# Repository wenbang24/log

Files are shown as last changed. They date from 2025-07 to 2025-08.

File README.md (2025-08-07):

# Log
A low-profile, wireless, portable rendition of the OLKB Planck keyboard.

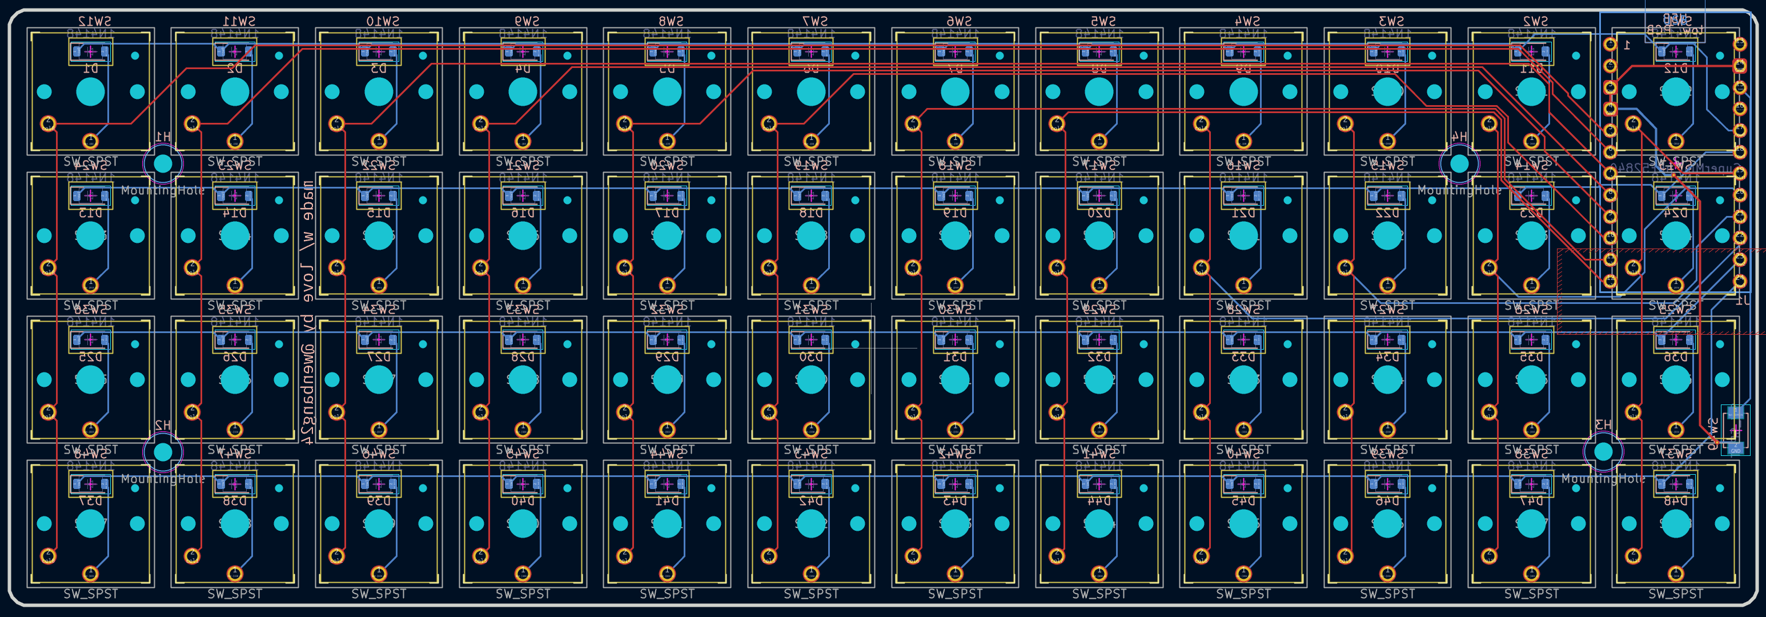
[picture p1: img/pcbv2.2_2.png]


# Firmware
Log uses [ZMK](https://zmk.dev/) for its firmware. The firmware is available in the `zmk-keyboard-log` sub-repo.

# BOM
| Part | Quantity | Price | Link |
| ---- | --- | ----- | ---- |
| Supermini nRF52840 | 1 | $4.45 | [AliExpress](https://www.aliexpress.com/item/1005007205026373.html) |
| Kailh Choc V1 | 48 | $21.77 | [AliExpress](https://www.aliexpress.com/item/1005004106505158.html) |
| 1N4148 Diode | 48 | included in PCB cost | [AliExpress](https://www.aliexpress.com/item/1005003208856262.html) |
| CFX Keycap Set | 1 | $27.76 | [AliExpress](https://www.aliexpress.com/item/1005005291084816.html) |
| M2x3 Heat-Set Inserts | 4 | $1.60 | [AliExpress](https://www.aliexpress.com/item/1005003582355741.html) |
| M2 Flat Head Screws 5mm | 4 | $1.25 | [AliExpress](https://www.aliexpress.com/item/1005008691176275.html) |
| 3.7V 5000mAh Battery | 1 | $9.64 | [AliExpress](https://www.aliexpress.com/item/1005006877616182.html) |

Total: $67.83

(prices converted from AUD to USD, as of 2025-07-16)

PCB & PCBA cost: $29.34

**TOTAL: $97.17**

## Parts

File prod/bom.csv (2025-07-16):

Part | Quantity | Price | Link
Supermini nRF52840 | 1 | $4.45 | https://www.aliexpress.com/item/1005007205026373.html
Kailh Choc V1 | 48 | $21.77 | https://www.aliexpress.com/item/1005004106505158.html
1N4148 Diode | 48 | $1.36 | https://www.aliexpress.com/item/1005003208856262.html
CFX Keycap Set | 1 | $27.76 | https://www.aliexpress.com/item/1005005291084816.html
M2x3 Heat-Set Inserts | 4 | $1.60 | https://www.aliexpress.com/item/1005003582355741.html
M2 Flat Head Screws 5mm | 4 | $1.25 | https://www.aliexpress.com/item/1005008691176275.html
3.7V 5000mAh Battery | 1 | $9.64 | https://www.aliexpress.com/item/1005006877616182.html

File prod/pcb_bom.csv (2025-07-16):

Designator | Footprint | Quantity | Value | LCSC Part #
D1, D10, D11, D12, D13, D14, D15, D16, D17, D18, D19, D2, D20, D21, D22, D23, D24, D25, D26, D27, D28, D29, D3, D30, D31, D32, D33, D34, D35, D36, D37, D38, D39, D4, D40, D41, D42, D43, D44, D45, D46, D47, D48, D5, D6, D7, D8, D9 | D_SOD-123 | 48 | 1N4148 | C81598
SW1, SW10, SW11, SW12, SW13, SW14, SW15, SW16, SW17, SW18, SW19, SW2, SW20, SW21, SW22, SW23, SW24, SW25, SW26, SW27, SW28, SW29, SW3, SW30, SW31, SW32, SW33, SW34, SW35, SW36, SW37, SW38, SW39, SW4, SW40, SW41, SW42, SW43, SW44, SW45, SW46, SW47, SW48, SW5, SW6, SW7, SW8, SW9 | SW_PG1350 | 48 | SW_SPST
SW49 | SW_TS-1088-AR02016 | 1 | SW_SPST | C720477

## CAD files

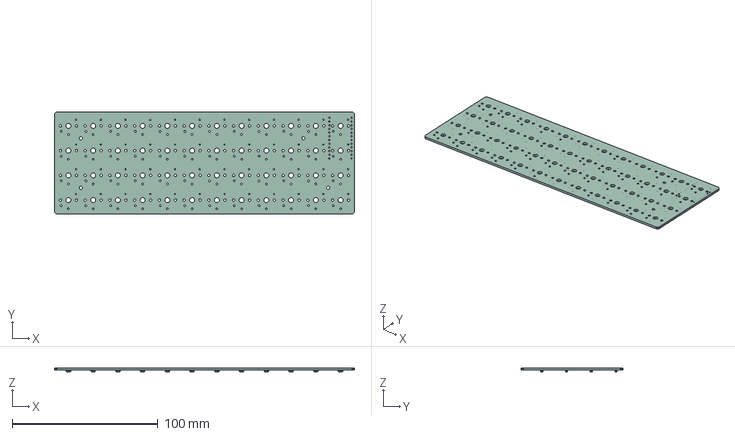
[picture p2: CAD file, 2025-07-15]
pcb/pcb.step
206.2 x 70.2 x 2.84 mm
D_SOD-123 x 48
pcb_PCB

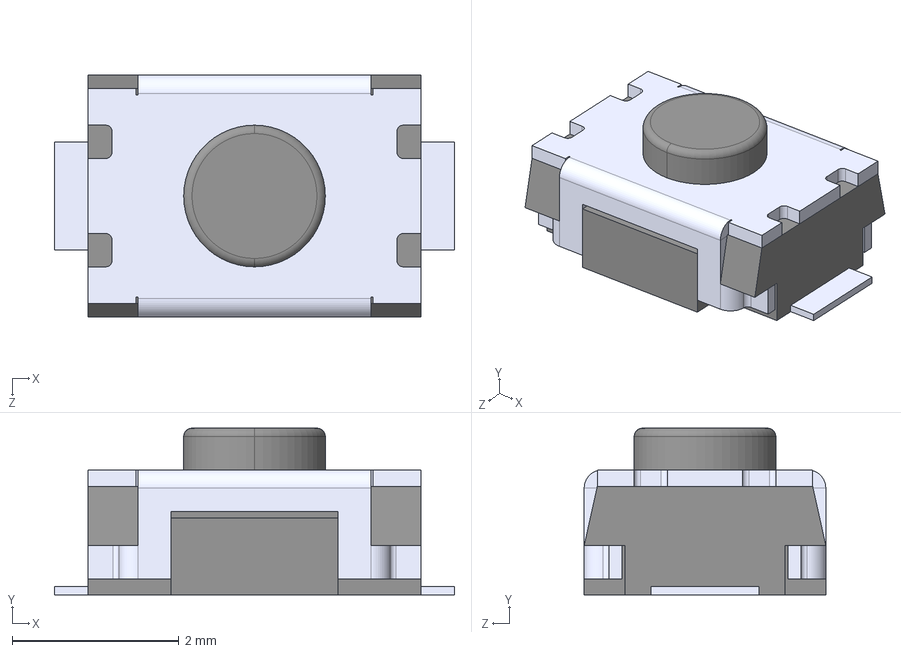
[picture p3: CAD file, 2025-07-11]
pcb/TS-1088-AR02016/TS-1088-AR02016.step
4.80 x 2.00 x 2.90 mm

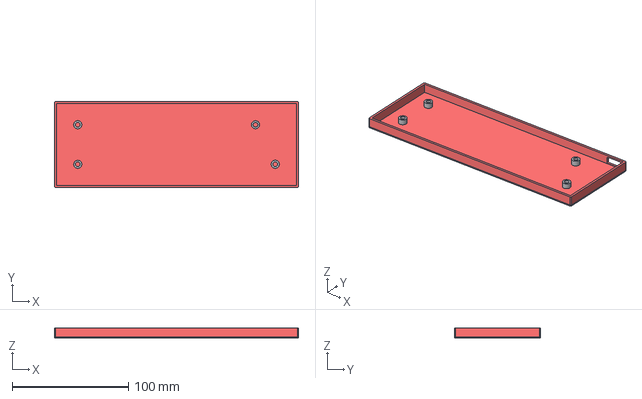
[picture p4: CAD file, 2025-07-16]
prod/case.step
210.0 x 74.0 x 8.60 mm

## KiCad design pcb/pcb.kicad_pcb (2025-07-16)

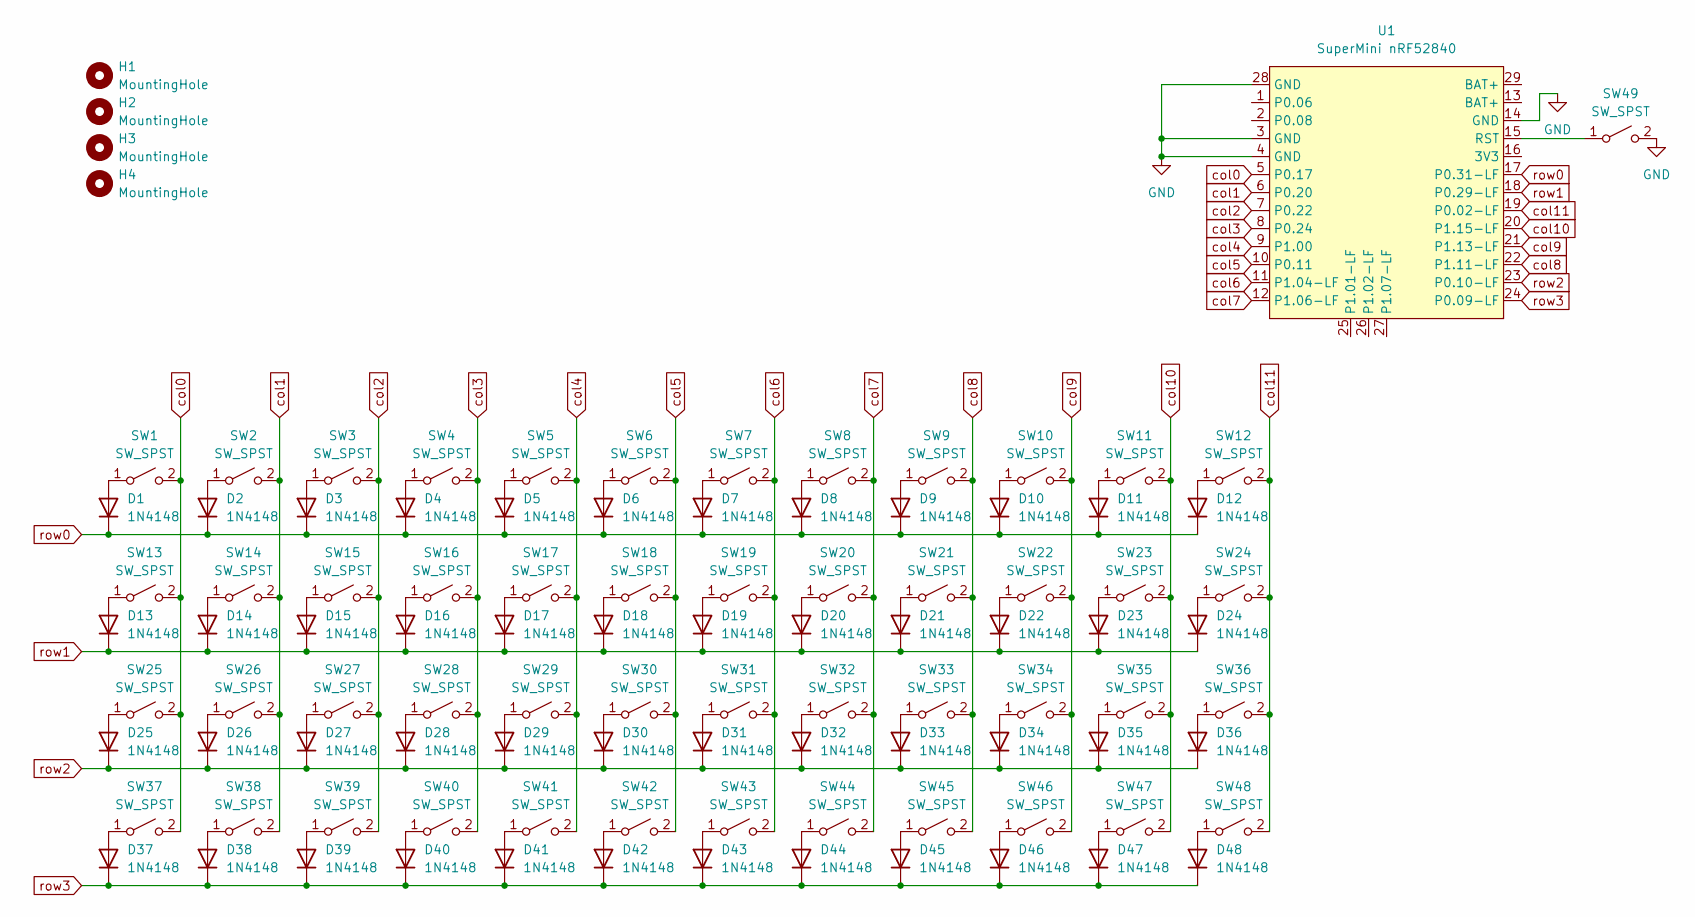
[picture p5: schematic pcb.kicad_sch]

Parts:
D1, D2, D3, D4, D5, D6, D7, D8, D9, D10, D11, D12, D13, D14, D15, D16, D17, D18, D19, D20, D21, D22, D23, D24, D25, D26, D27, D28, D29, D30, D31, D32, D33, D34, D35, D36, D37, D38, D39, D40, D41, D42, D43, D44, D45, D46, D47, D48: 1N4148; D_SOD-123; LCSC C81598
H1, H2, H3, H4: MountingHole; MountingHole_2.2mm_M2
SW1, SW2, SW3, SW4, SW5, SW6, SW7, SW8, SW9, SW10, SW11, SW12, SW13, SW14, SW15, SW16, SW17, SW18, SW19, SW20, SW21, SW22, SW23, SW24, SW25, SW26, SW27, SW28, SW29, SW30, SW31, SW32, SW33, SW34, SW35, SW36, SW37, SW38, SW39, SW40, SW41, SW42, SW43, SW44, SW45, SW46, SW47, SW48: SW_SPST; SW_PG1350
SW49: SW_SPST; SW_TS-1088-AR02016; LCSC C720477
U1: SuperMini nRF52840; SuperMini_nRF52840_H_USBdn

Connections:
GND: SW49.2 (B), U1.3 (GND), U1.4 (GND), U1.14 (GND), U1.28 (GND)
unnamed: D1.2 (A), SW1.1 (A)
unnamed: D2.2 (A), SW2.1 (A)
unnamed: D3.2 (A), SW3.1 (A)
unnamed: D4.2 (A), SW4.1 (A)
unnamed: D5.2 (A), SW5.1 (A)
unnamed: D6.2 (A), SW6.1 (A)
unnamed: D7.2 (A), SW7.1 (A)
unnamed: D8.2 (A), SW8.1 (A)
unnamed: D9.2 (A), SW9.1 (A)
unnamed: D10.2 (A), SW10.1 (A)
unnamed: D11.2 (A), SW11.1 (A)
unnamed: D12.2 (A), SW12.1 (A)
unnamed: D13.2 (A), SW13.1 (A)
unnamed: D14.2 (A), SW14.1 (A)
unnamed: D15.2 (A), SW15.1 (A)
unnamed: D16.2 (A), SW16.1 (A)
unnamed: D17.2 (A), SW17.1 (A)
unnamed: D18.2 (A), SW18.1 (A)
unnamed: D19.2 (A), SW19.1 (A)
unnamed: D20.2 (A), SW20.1 (A)
unnamed: D21.2 (A), SW21.1 (A)
unnamed: D22.2 (A), SW22.1 (A)
unnamed: D23.2 (A), SW23.1 (A)
unnamed: D24.2 (A), SW24.1 (A)
unnamed: D25.2 (A), SW25.1 (A)
unnamed: D26.2 (A), SW26.1 (A)
unnamed: D27.2 (A), SW27.1 (A)
unnamed: D28.2 (A), SW28.1 (A)
unnamed: D29.2 (A), SW29.1 (A)
unnamed: D30.2 (A), SW30.1 (A)
unnamed: D31.2 (A), SW31.1 (A)
unnamed: D32.2 (A), SW32.1 (A)
unnamed: D33.2 (A), SW33.1 (A)
unnamed: D34.2 (A), SW34.1 (A)
unnamed: D35.2 (A), SW35.1 (A)
unnamed: D36.2 (A), SW36.1 (A)
unnamed: D37.2 (A), SW37.1 (A)
unnamed: D38.2 (A), SW38.1 (A)
unnamed: D39.2 (A), SW39.1 (A)
unnamed: D40.2 (A), SW40.1 (A)
unnamed: D41.2 (A), SW41.1 (A)
unnamed: D42.2 (A), SW42.1 (A)
unnamed: D43.2 (A), SW43.1 (A)
unnamed: D44.2 (A), SW44.1 (A)
unnamed: D45.2 (A), SW45.1 (A)
unnamed: D46.2 (A), SW46.1 (A)
unnamed: D47.2 (A), SW47.1 (A)
unnamed: D48.2 (A), SW48.1 (A)
unnamed: SW49.1 (A), U1.15 (RST)
col0: SW1.2 (B), SW13.2 (B), SW25.2 (B), SW37.2 (B), U1.5 (P0.17)
col1: SW2.2 (B), SW14.2 (B), SW26.2 (B), SW38.2 (B), U1.6 (P0.20)
col2: SW3.2 (B), SW15.2 (B), SW27.2 (B), SW39.2 (B), U1.7 (P0.22)
col3: SW4.2 (B), SW16.2 (B), SW28.2 (B), SW40.2 (B), U1.8 (P0.24)
col4: SW5.2 (B), SW17.2 (B), SW29.2 (B), SW41.2 (B), U1.9 (P1.00)
col5: SW6.2 (B), SW18.2 (B), SW30.2 (B), SW42.2 (B), U1.10 (P0.11)
col6: SW7.2 (B), SW19.2 (B), SW31.2 (B), SW43.2 (B), U1.11 (P1.04-LF)
col7: SW8.2 (B), SW20.2 (B), SW32.2 (B), SW44.2 (B), U1.12 (P1.06-LF)
col8: SW9.2 (B), SW21.2 (B), SW33.2 (B), SW45.2 (B), U1.22 (P1.11-LF)
col9: SW10.2 (B), SW22.2 (B), SW34.2 (B), SW46.2 (B), U1.21 (P1.13-LF)
col10: SW11.2 (B), SW23.2 (B), SW35.2 (B), SW47.2 (B), U1.20 (P1.15-LF)
col11: SW12.2 (B), SW24.2 (B), SW36.2 (B), SW48.2 (B), U1.19 (P0.02-LF)
row0: D1.1 (K), D2.1 (K), D3.1 (K), D4.1 (K), D5.1 (K), D6.1 (K), D7.1 (K), D8.1 (K), D9.1 (K), D10.1 (K), D11.1 (K), D12.1 (K), U1.17 (P0.31-LF)
row1: D13.1 (K), D14.1 (K), D15.1 (K), D16.1 (K), D17.1 (K), D18.1 (K), D19.1 (K), D20.1 (K), D21.1 (K), D22.1 (K), D23.1 (K), D24.1 (K), U1.18 (P0.29-LF)
row2: D25.1 (K), D26.1 (K), D27.1 (K), D28.1 (K), D29.1 (K), D30.1 (K), D31.1 (K), D32.1 (K), D33.1 (K), D34.1 (K), D35.1 (K), D36.1 (K), U1.23 (P0.10-LF)
row3: D37.1 (K), D38.1 (K), D39.1 (K), D40.1 (K), D41.1 (K), D42.1 (K), D43.1 (K), D44.1 (K), D45.1 (K), D46.1 (K), D47.1 (K), D48.1 (K), U1.24 (P0.09-LF)

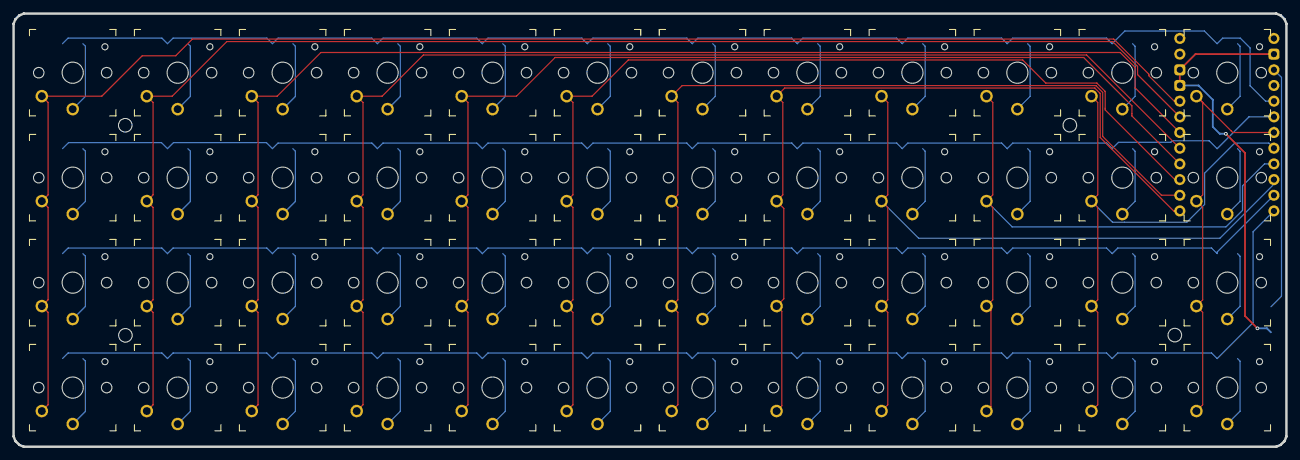
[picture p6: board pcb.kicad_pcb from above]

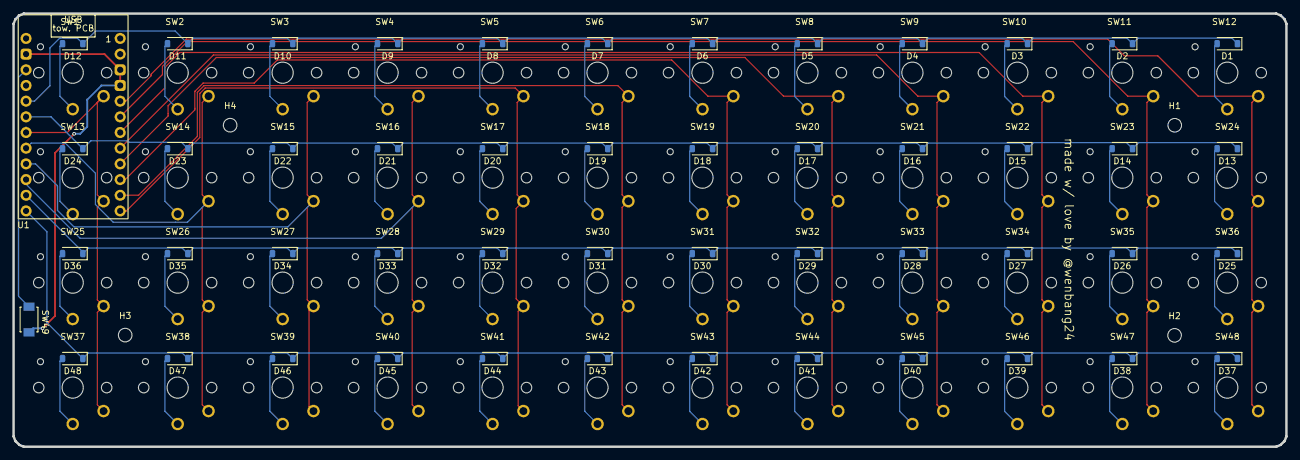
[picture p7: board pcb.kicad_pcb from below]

Board: 2 copper layers, 206.1 x 70.2 mm, 102 parts (50 on the bottom side), 66 nets.

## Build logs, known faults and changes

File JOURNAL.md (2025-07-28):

---
title: "Log"
author: "Ben Wang"
description: "A low-profile rendition of the OLKB Planck for portability"
created_at: "2025-06-15"
---

Total time spent so far: 21 hrs

# July 9 2025
Finished my other projects so I can start work on this one (lol)
- Researched parts, form factor, controller, etc.
- Decided on Supermini nrf52840 for controller
- Made initial PCB (just the keys and the layout)

Time spent: 4 hrs

# July 11 2025
- Finished layout of keys & diodes
- Connected switch matrix to controller
- Routed PCB
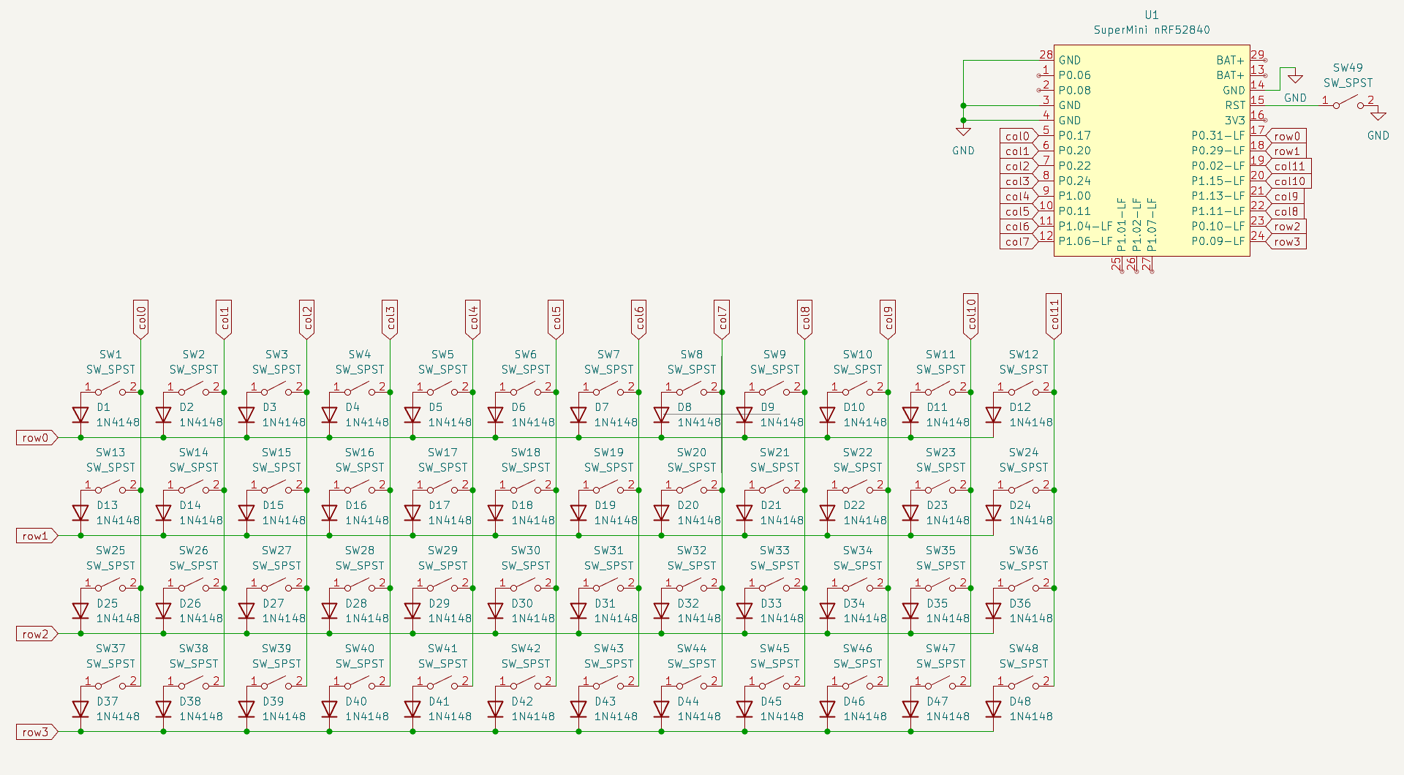
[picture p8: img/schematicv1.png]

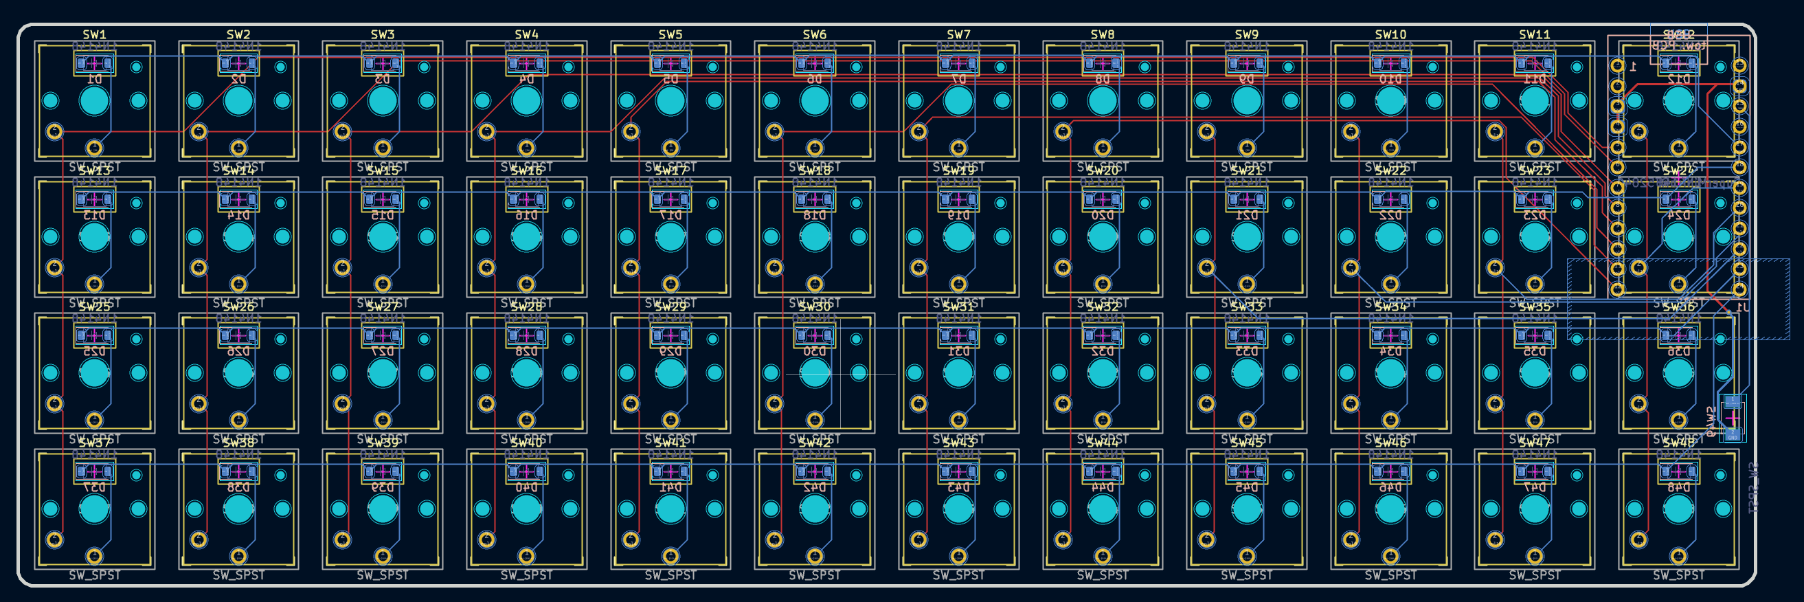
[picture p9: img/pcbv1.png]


Time spent: 4 hrs

# July 13 2025
- Made ZMK firmware for the board
- Redid the PCB for 17x17 CFX spacing
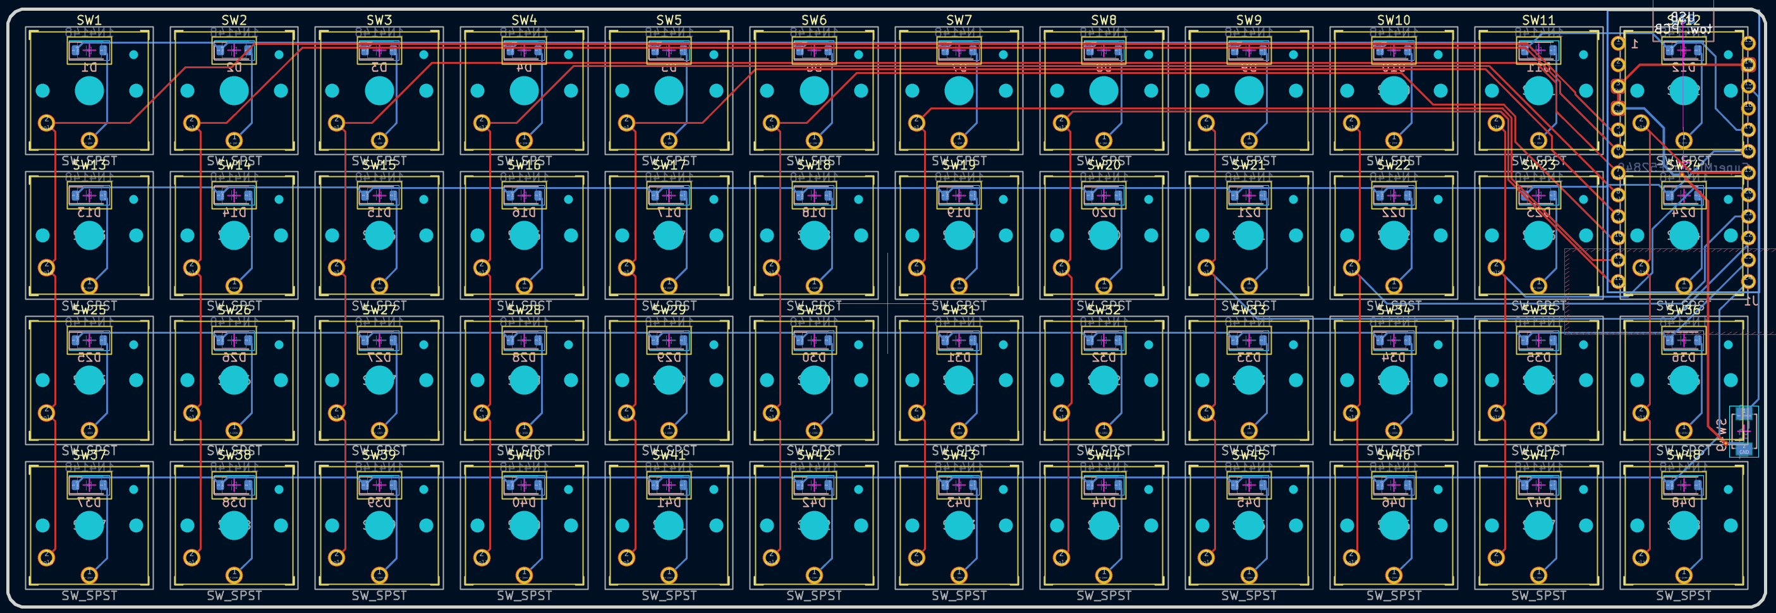
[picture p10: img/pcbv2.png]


Time spent: 5 hrs

# July 15 2025
- Added mounting holes
- Made a rudimentary case
- Spent way too long researching heat-set inserts and batteries

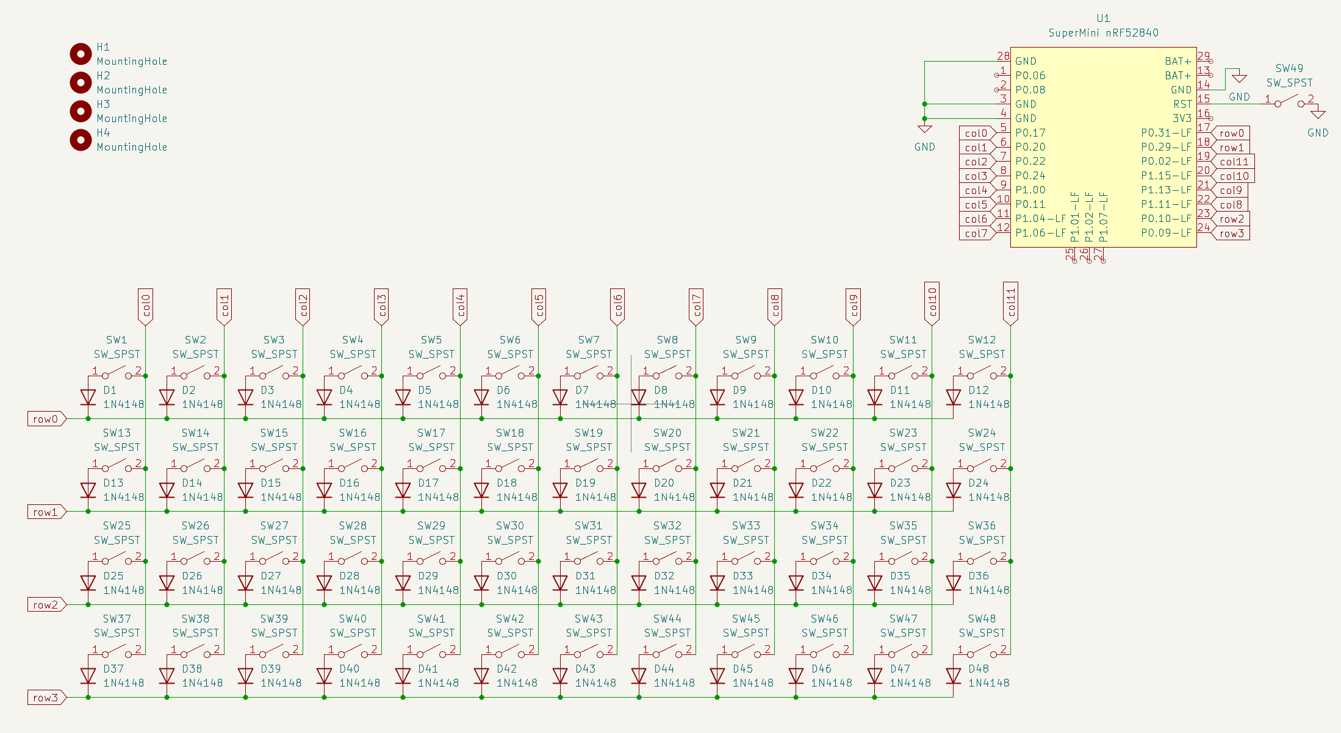
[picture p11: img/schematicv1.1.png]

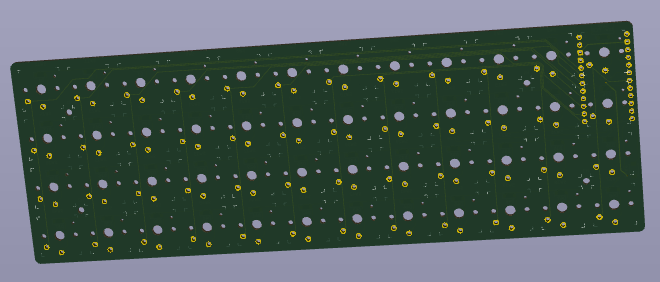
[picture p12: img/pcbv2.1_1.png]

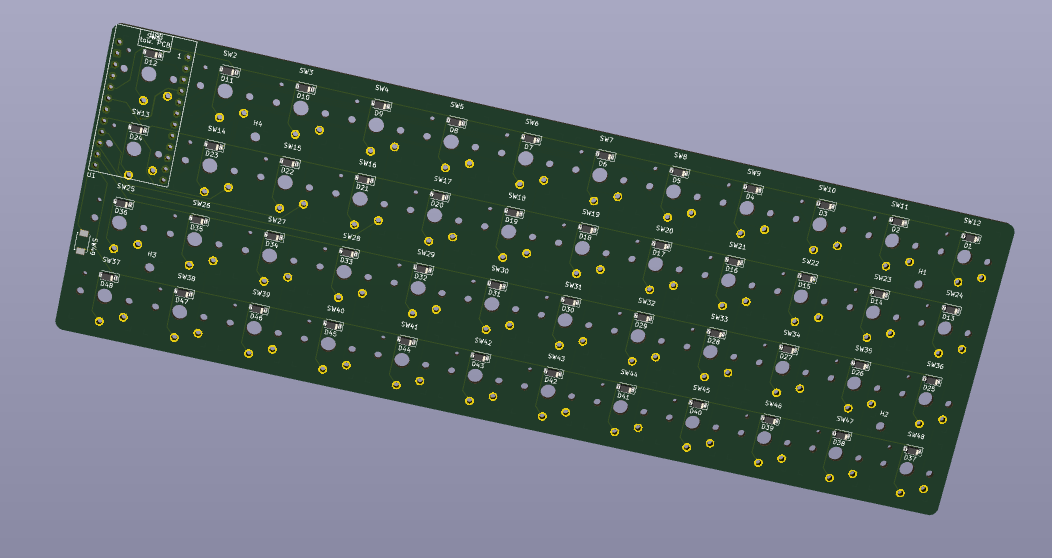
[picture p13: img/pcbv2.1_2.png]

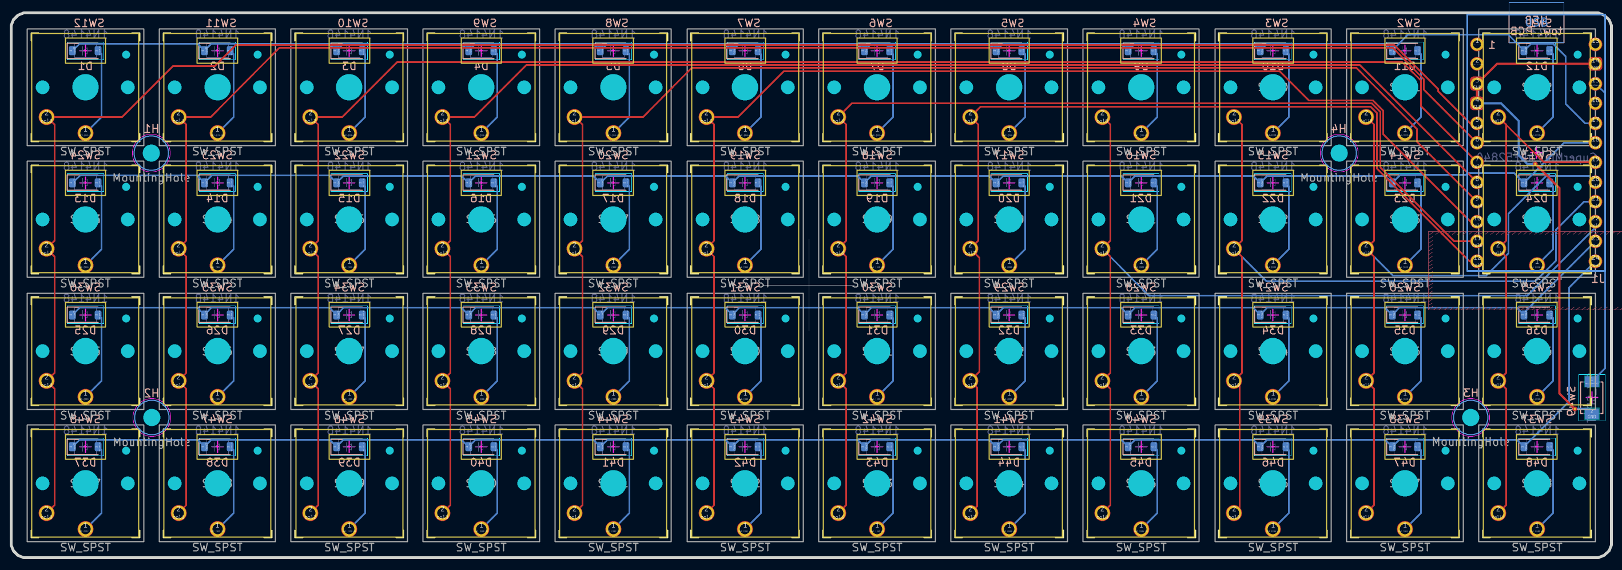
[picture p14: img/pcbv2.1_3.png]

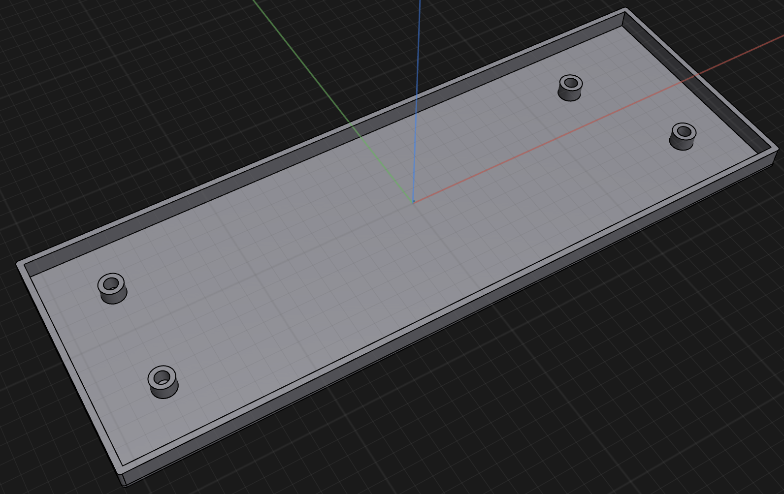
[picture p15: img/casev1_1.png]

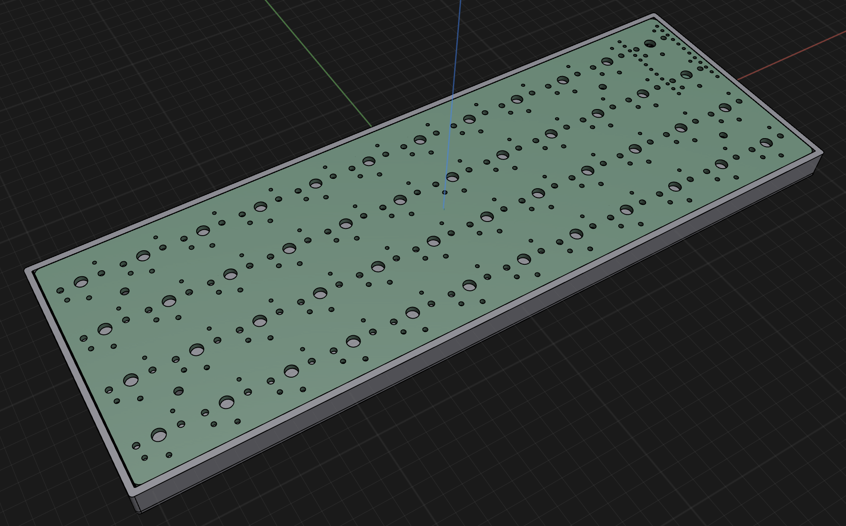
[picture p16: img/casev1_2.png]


Time spent: 4 hrs

# July 16 2025
- Rendered
- Researched & BOM'ed
- Add a lil' smth to the pcb :)
- Add a hole for the USB-C port


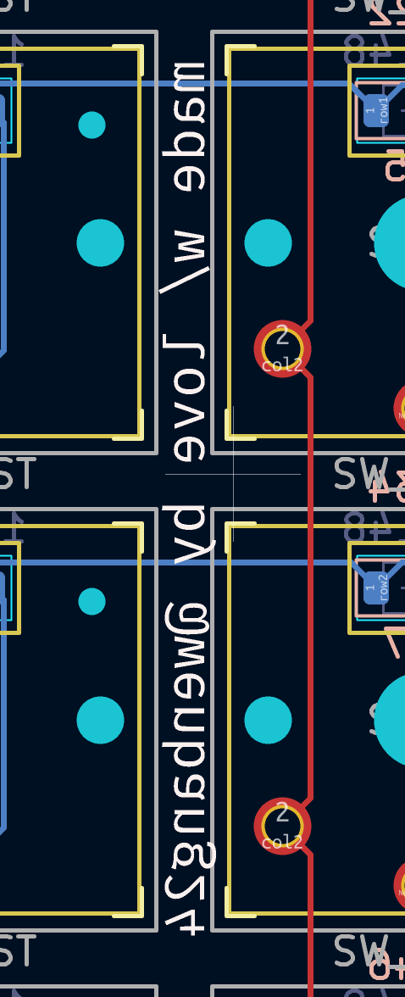
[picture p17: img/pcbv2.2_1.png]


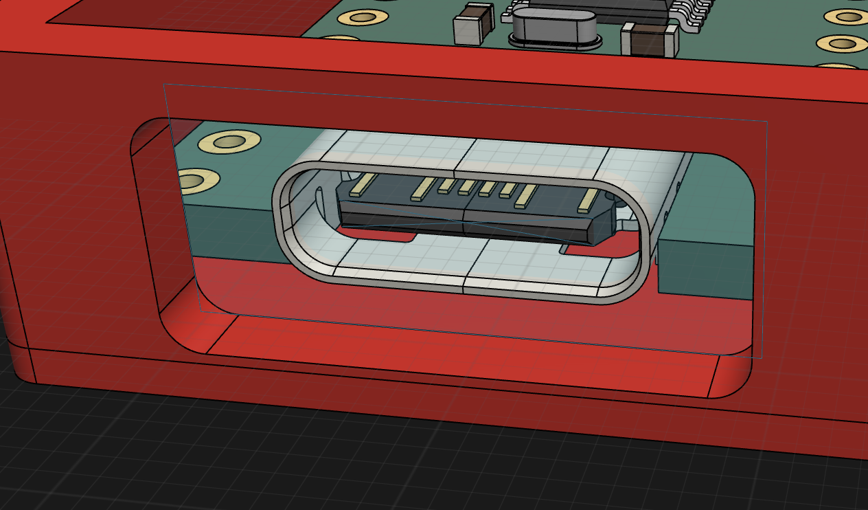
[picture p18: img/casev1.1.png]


Time spent: 3 hrs

# July 26 2025
- Added prod folder
- Made some way better renders

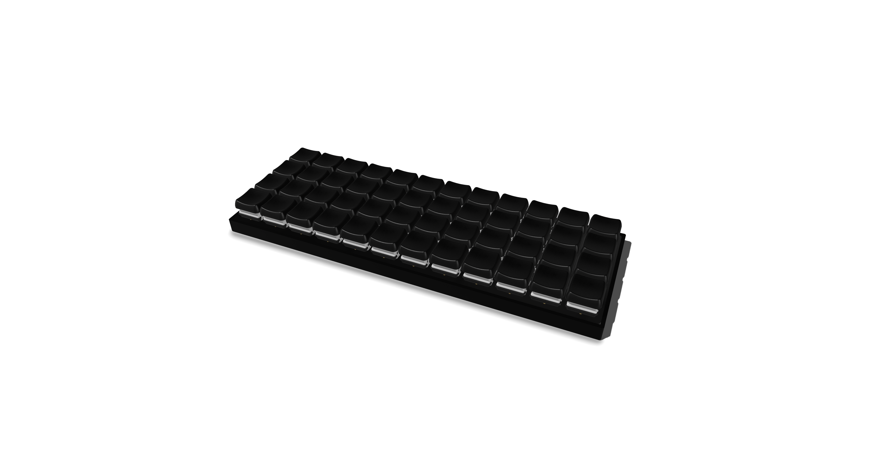
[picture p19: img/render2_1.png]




Time spent: 1 hr

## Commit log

2025-07-10 initial pcb
    [pcb.kicad_pcb, pcb.kicad_sch]
2025-07-11 pcb v1 done
    [TS-1088-AR02016.step, pcb.kicad_pcb, pcb.kicad_sch]
2025-07-13 small schematic changes
    [pcb.kicad_sch]
2025-07-13 firmware completed & CFX spacing
    [freerouting.dsn, pcb.kicad_pcb, temp-freerouting.dsn]
2025-07-15 holes and cases
    [pcb.kicad_pcb, pcb.kicad_sch, pcb.step]
2025-07-16 BOM & render
    [bom.csv, designators.csv, pcb.kicad_pcb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]
2025-07-16 add bom to root
    [bom.csv]
2025-07-16 render, bom, finishing touches'
    [case.step, pcb.kicad_pcb]
2025-07-16 finishing touches
    [temp-freerouting.dsn]
2025-07-27 prod folder
    [bom.csv, case.step, positions.csv]
2025-07-27 wrong bom
    [bom.csv]
2025-07-27 new bom
    [pcb_bom.csv]
2025-08-07 add pcb to readme
